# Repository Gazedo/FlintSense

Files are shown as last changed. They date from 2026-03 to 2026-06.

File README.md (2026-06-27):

# FlintMesh — Wildfire Early Warning Sensor Network

A distributed, solar-powered LoRa sensor network that measures fire-weather
conditions in real time.  Nodes report data compatible with the
[Fire Weather Index (FWI)](https://cwfis.cfs.nrcan.gc.ca/background/summary/fwi) and
[NFDRS](https://www.wfas.net/index.php/nfdrs-fire-danger-model-fire-danger-8) frameworks
used by land managers and fire agencies.

Built in Rust — `no_std` Embassy async firmware on ESP32 nodes, `std` gateway on
Raspberry Pi.

---

## Architecture

```
┌─────────────────────────────────────────────────────────────┐
│                        LoRa Mesh                            │
│                                                             │
│   [Sensor Node] ──LoRa──▶ [Bridge Node] ──LoRa──▶ [Gateway] │
│   (flint-node)           (flint-bridge)         (flint-   │
│                                                    gateway) │
└─────────────────────────────────────────────────────────────┘
         │                                        │
         │  Embassy async / no_std                │  std / Tokio
         │  ESP32                                 │  Raspberry Pi
                                                  │
                                           InfluxDB + Grafana
```

Mesh routing uses flood routing with hop-limit deduplication — the same
semantics as [Meshtastic](https://meshtastic.org/).  All packet types and
routing logic live in the shared `flint-proto` crate so embedded nodes and
the gateway always agree on the wire format.

---

## Crates

| Crate | Target | Description |
|---|---|---|
| [`flint-proto`](./flint-proto) | `no_std` (any) | Shared packet types, mesh envelope, seen-packet cache, postcard encode/decode |
| [`flint-bridge`](./flint-bridge) | `xtensa-esp32-none-elf` | LoRa RX + transparent mesh relay + USB binary bridge on Heltec WiFi LoRa 32 V2 |
| [`flint-node`](./flint-node) | `xtensa-esp32-none-elf` | Sensor node firmware on Heltec WiFi LoRa 32 V2 (TX test → real sensors in progress) |
| `flint-gateway` | host (RPi) | Serial reader/decoder for the bridge stream (InfluxDB + Grafana integration planned) |

---

## Sensor Measurements

| Measurement | Sensor | Interface |
|---|---|---|
| Air temperature + relative humidity | SHT40 | I2C 0x44 |
| Barometric pressure | BME280 | I2C |
| Wind speed + direction | Anemometer + vane | GPIO pulse count |
| Dead fuel moisture proxy | Wood dowel + resistive probes | ADC |
| Battery state-of-charge | MAX17048 fuel gauge | I2C 0x36 |

---

## Hardware

### Development (Phase 0) — current
- **Heltec WiFi LoRa 32 V2** — ESP32 + SX1276 + OLED, used for all firmware
  development.  Two boards: one running `flint-node` (TX), one running
  `flint-bridge` (RX + relay + USB bridge).

### Production Node (Phase 1)
- **M5Stack Stamp-C3U** (ESP32-C3, ~5 µA deep sleep) + harvested SX1276
- Custom KiCad PCB: Stamp-C3U + SX1276 + MAX17048 + TP4056 + solar input + sensor headers
- Fabricated at JLCPCB/PCBWay
- 3D-printed weatherproof enclosure

### Gateway
- Raspberry Pi + Heltec V2 as LoRa receiver
- InfluxDB / TimescaleDB for time-series storage
- Grafana dashboard (public)

---

## Getting Started

### Prerequisites

```bash
cargo install espup && espup install   # Xtensa toolchain + export-esp.sh
cargo install espflash
```

Add to `~/.zshrc` (or source before each session):
```bash
. $HOME/export-esp.sh
```

Mac: install the [CP2102 USB driver](https://www.silabs.com/developers/usb-to-uart-bridge-vcp-drivers)
before connecting any board.

### Build

```bash
# Build all crates
cargo build --workspace

# Or a single crate
cargo build -p flint-node
cd flint-bridge && cargo build
```

### Flash & Monitor

Set your USB port in `.cargo/config.toml` (workspace root), then:

```bash
# Flash and open serial monitor
cd flint-node   && cargo run --release
cd flint-bridge && cargo run --release
```

Log output streams over UART via `espflash --monitor`.

### Documentation

```bash
cargo doc --workspace --no-deps --open
```

---

## Bring-up Sequence

| Step | Status | Description |
|---|---|---|
| 1 | ✅ | **Arduino loopback** — confirmed RF link on two Heltec V2 boards |
| 2 | ✅ | **Rust RX ↔ Arduino TX** — `flint-bridge` receiving from factory firmware, validated `lora-phy` config |
| 3 | ✅ | **Full Rust both sides** — `flint-node` TX and `flint-bridge` RX passing `MeshEnvelope` packets end-to-end |
| 4 | 🔄 | **Sensor integration** — fuel moisture (ADC resistive dowel), SHT40 (I2C), MAX17048 (I2C) |
| 5 | ⬜ | **Anemometer pulse counting** — GPIO interrupt task |
| 6 | ⬜ | **RPi gateway** — `flint-gateway` receiving packets, writing to InfluxDB |
| 7 | ⬜ | **SDR passive monitor** — `gr-lora_sdr` chirp waterfall for demos and debugging |

---

## Packet Format

Wire format is [postcard](https://github.com/jamesmunns/postcard)-encoded
`MeshEnvelope<FlintPayload>`, approximately 20–24 bytes per sensor reading.

```
MeshEnvelope {
    from:       u32   // node ID (lower 4 bytes of MAC)
    to:         u32   // 0xFFFFFFFF = broadcast
    packet_id:  u32   // random, used for dedup
    hop_limit:  u8    // decremented on each relay (default 3)
    hop_start:  u8    // original hop_limit
    payload:    FlintPayload::SensorReading {
        node_id:       u8
        temp_c:        i16   // °C × 100
        humidity_pct:  u8
        wind_speed_ms: u8    // m/s × 2
        wind_dir_deg:  u16
        fuel_moisture: u8    // 0–100 %, resistive wood dowel
        battery_soc:   u8
        battery_mv:    u16
        sequence:      u16
    }
}
```

---

## License

MIT OR Apache-2.0

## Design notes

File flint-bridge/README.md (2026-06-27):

# flint-bridge

LoRa receive + transparent mesh relay + **USB bridge** firmware for the
**Heltec WiFi LoRa 32 V2** (ESP32 + SX1276).

`flint-bridge` receives `MeshEnvelope` packets off the air, relays unseen ones,
and **reports every reception to the host over USB as binary records** that
`flint-gateway` decodes with the shared `flint-proto` definitions. The same
record format is what a LoRa radio wired directly into the gateway would emit, so
the host decode path is source-agnostic.

(The crate was formerly `flint-debug`, a human-readable watch tool. Its watch
behaviour now lives in the on-demand **debug mode** below; a standalone watch
tool can be re-created later if wanted.)

## Output modes

The bridge starts in **binary mode** and accepts single-byte commands on USB
serial:

| Command | Mode | Behaviour |
|---|---|---|
| `b` | Binary (default) | Logs suppressed (`set_max_level(Off)`); emits binary `FrameReport`/`RawFrame` records. Clean machine-parseable stream. |
| `d` | Debug | Raises logs to trace; renders frames as human-readable text *instead of* binary — for debugging the bridge itself. |

Commands are idempotent, so a host can send `b` on connect to force a known
state. Unknown bytes are ignored.

## Wire format

Records are defined in `flint-proto` (`bridge` module): a self-delimiting frame
`[sync][tag][len][body][CRC-16]`. `FrameReport` (tag `0x01`) carries link quality
(`rssi`/`snr`/`len`), the receiver's disposition (relayed / local-only /
duplicate), and the received envelope bytes. `RawFrame` (tag `0x02`) carries link
quality plus the raw bytes of any packet that did not decode as a `MeshEnvelope`.
The sync word + length + CRC let the host skip stray boot/panic text and resync.

## Hardware

Heltec WiFi LoRa 32 V2 pin mapping:

| Signal | GPIO |
|---|---|
| SPI SCK | 5 |
| SPI MISO | 19 |
| SPI MOSI | 27 |
| SX1276 CS | 18 |
| SX1276 RST | 14 |
| SX1276 DIO0 | 26 |
| SX1276 DIO1 | 35 |

## Configuration

Before flashing, set your USB port in `.cargo/config.toml`:

```toml
[target.xtensa-esp32-none-elf]
runner = "espflash flash --monitor --baud 921600 --port /dev/cu.usbserial-XXXX"
```

`ESP_LOG = "TRACE"` is set in `.cargo/config.toml` so debug mode can reach trace
level; the runtime gate (`log::set_max_level`) keeps logs off in binary mode.

LoRa modem config (SF / BW / CR / frequency / sync word) is set in `src/main.rs`.
Match these values to your transmitter.

## Build & Flash

```bash
# From workspace root — requires Xtensa toolchain (espup install)
cd flint-bridge
cargo run --release
```

To read the binary stream on the host, run the gateway against the same port:

```bash
cd flint-gateway
cargo run -- /dev/cu.usbserial-XXXX
```

Or send `d` in a serial monitor to eyeball frames directly from the bridge.

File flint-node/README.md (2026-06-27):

# flint-node

LoRa transmit test firmware for the **Heltec WiFi LoRa 32 V2** (ESP32 + SX1276).

Sends a `MeshEnvelope` containing a fake `WeatherPacket` every 5 seconds.
Use alongside `flint-bridge` on a second board to verify the full TX → RX → decode
path before connecting real sensors.

## Hardware

Heltec WiFi LoRa 32 V2 pin mapping:

| Signal | GPIO |
|---|---|
| SPI SCK | 5 |
| SPI MISO | 19 |
| SPI MOSI | 27 |
| SX1276 CS | 18 |
| SX1276 RST | 14 |
| SX1276 DIO0 | 26 |
| OLED SDA | 4 |
| OLED SCL | 15 |
| OLED RST | 16 |

## Configuration

Set your USB port in `.cargo/config.toml`:

```toml
[target.xtensa-esp32-none-elf]
runner = "espflash flash --monitor --baud 921600 --port /dev/cu.usbserial-XXXX"
```

LoRa modem settings (`LORA_FREQUENCY_HZ`, `LORA_SF`, `LORA_BW`, `LORA_CR`) are
constants at the top of `src/main.rs` and **must match** the values in
`flint-bridge` exactly.

`NODE_ADDR` and `NODE_ID` are hardcoded test values. When real sensor hardware
is added these will be derived from the chip MAC address.

## Build & Flash

```bash
# From the flint-node directory
cargo run --release
```

Requires the Xtensa ESP32 Rust toolchain (`espup install`).
The `rust-toolchain.toml` in the workspace root pins the correct toolchain
automatically.

## OLED output

```
FlintNode TX
TX: 3
```

Counter increments after each successful transmission.

## Serial output

```
INFO flint-node booting
INFO TX loop — 915000000Hz  SF7  BW125KHz  CR4_5  5000ms interval
INFO TX seq=0 (N bytes)
INFO TX seq=1 (N bytes)
...
```

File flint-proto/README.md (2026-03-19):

# flint-proto

Shared packet types and mesh routing primitives for the FlintSense sensor
network.

This crate is `no_std` and is a dependency of every other crate in the
workspace — embedded sensor nodes, the debug/relay node, and the Raspberry Pi
gateway all use the same types to guarantee wire-format compatibility.

## Contents

| Item | Description |
|---|---|
| `WeatherPacket` | Fire-weather sensor reading (temperature, humidity, wind, fuel moisture, battery) |
| `FlintPayload` | Enum of all application-layer message types |
| `MeshEnvelope` | Flood-routing wrapper — same hop-limit semantics as Meshtastic |
| `SeenCache` | Fixed-capacity ring cache for seen-packet deduplication |
| `encode` / `decode` | postcard serialization helpers |

## Feature Flags

| Feature | Description |
|---|---|
| `defmt` | Derives `defmt::Format` on all public types for RTT logging on embedded targets |

## Generating Docs

```bash
cargo doc -p flint-proto --open
```

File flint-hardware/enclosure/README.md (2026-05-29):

# FlintMesh Sensor Enclosure

Parametric Build123d model for the FlintMesh outdoor weatherproof sensor enclosure.
Mounts to a 2-inch steel pole. Designed for Nampa, Idaho conditions — intense heat,
high UV, and strong wind gusts.

---

## Components

| File exported | Description | Print notes |
|---|---|---|
| `enclosure_body.stl` | Main box, open top | PETG or ASA — UV stable |
| `lid.stl` | Flat lid with skirt | PETG or ASA |
| `pole_clamp_half.stl` | One half of split-ring clamp | Print × 2 |
| `solar_bracket.stl` | South-facing tilted panel mount | PETG or ASA |
| `anemometer_mount.stl` | 1-inch post stub + flange | PETG |
| `rain_sensor_bracket.stl` | L-bracket with forward tilt | PETG |

---

## Dependencies

```
build123d >= 0.10.0
bd-warehouse >= 0.2.0
```

Install with uv (recommended — already in `pyproject.toml`):

```bash
cd flint-hardware
uv sync
```

Or with pip:

```bash
pip install build123d bd-warehouse
```

For live 3D preview in VS Code, install the OCP CAD Viewer extension:

```bash
pip install ocp_vscode
```

---

## Running

Export all STL and STEP files to `enclosure/exports/`:

```bash
cd flint-hardware
uv run python enclosure/flint_enclosure.py
```

For live preview while editing in VS Code with the OCP CAD Viewer extension,
add this to the bottom of a scratch script:

```python
from ocp_vscode import show
from enclosure.flint_enclosure import build_assembly
show(build_assembly(explode=True))
```

---

## Modifying Parameters

Every dimension is defined in the `Params` dataclass at the top of
`flint_enclosure.py`. Nothing is hard-coded in the geometry functions.

To change a value, edit the relevant sub-dataclass default:

```python
# Make the enclosure taller
@dataclass(frozen=True)
class _EnclosureParams:
    height: float = 90.0  # was 75.0
```

Or override at call time without touching the defaults:

```python
from enclosure.flint_enclosure import build_enclosure_body, Params, _EnclosureParams

custom = Params(enc=_EnclosureParams(height=90.0, width=150.0))
body = build_enclosure_body(custom)
```

---

## Fastener Reference

All fasteners are metric with captive hex nuts. Nothing requires a nut to be
held from inside the enclosure during field assembly.

| Location | Fastener | Nut |
|---|---|---|
| Lid to body (× 4) | M3 × 12 SHCS | M3 hex captive in body boss |
| PCB standoffs (× 4) | M3 × 10 SHCS | Tapped boss |
| Anemometer flange (× 4) | M4 × 20 SHCS | M4 hex captive in lid |
| Solar bracket feet (× 4) | M4 × 16 SHCS | M4 hex captive in lid |
| Solar panel to bracket (× 4) | M4 × 16 SHCS | M4 hex captive in bracket |
| Pole clamp halves (× 2) | M5 × 45 SHCS | M5 hex captive in ear tab |
| Rain sensor (× 4) | M3 × 12 SHCS | M3 hex captive in wall |

SHCS = Socket Head Cap Screw

---

## Design Rationale

### Louver vents
Blades are angled 45° below horizontal — the same principle as a Stevenson
screen used in professional weather stations. Rain cannot drive straight
through, but air circulates freely past the BME680. Vent area is centred on
the middle third of each long wall to avoid the wetter lower zone near the
ground.

### Solar tilt
35° from horizontal. Nampa, ID sits at approximately 43.5°N latitude. Fixed
tilt equal to latitude maximises annual yield; the 35° value is slightly
below latitude to bias toward summer output when irradiance is highest and
the heat load on the electronics is greatest.

### Pole clamp
Split-ring design. One half is permanently attached to the enclosure rear
wall (four M4 screws); the second half is a field piece. Tightening the two
M5 clamp bolts cinches the ring around the pole. The ring wall is 8 mm thick
which provides enough contact area to resist wind loading without cracking
printed PETG.

### Material
ASA is preferred over PETG for all exterior-facing parts (body, lid, solar
bracket). ASA is significantly more UV stable and dimensionally stable at
high ambient temperatures — both important in Nampa summers. PETG is
acceptable for sheltered parts (pole clamp interior, rain sensor bracket if
mounted on the shaded side).

---

## Future Expansion

The file is structured so that new components are additive. To add a new
mount or bracket:

1. Add a `_MyNewParams` dataclass in the Parameters section
2. Add a `my_new_field: _MyNewParams = _MyNewParams()` line to `Params`
3. Write a `build_my_component(p: Params) -> Compound` function following
   the same pattern as the existing builders
4. Add it to `build_assembly()` and `export_all()`

Planned future components (not yet modelled):
- Hinged front access door with gasket groove
- Separate battery compartment tray
- Wind vane (direction) mount alongside anemometer
- Secondary conduit entry on side wall
- Version 2 pole clamp with stainless U-bolt option

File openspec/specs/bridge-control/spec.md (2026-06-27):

# bridge-control Specification

## Purpose

Defines how the host controls the `flint-bridge` output mode over the USB serial
link, including the binary/debug mode command channel and the behaviour of each
mode.

## Requirements

### Requirement: Host-to-device command channel

`flint-bridge` SHALL listen on the USB serial port for single-byte commands from
the host while continuing to receive LoRa frames. The byte `b` selects binary
output mode and the byte `d` selects debug output mode. Commands MUST be
idempotent — sending the byte for the current mode leaves the bridge in that
mode — so a reconnecting host can force a known state. Unrecognised bytes MUST be
ignored without disrupting frame reception.

#### Scenario: Host selects debug mode

- **WHEN** the host sends `d` over serial
- **THEN** the bridge enters debug mode

#### Scenario: Host forces binary mode

- **WHEN** the host sends `b` while already in binary mode
- **THEN** the bridge remains in binary mode and continues emitting binary records

#### Scenario: Unknown command is ignored

- **WHEN** the host sends a byte other than `b` or `d`
- **THEN** the bridge ignores it and continues receiving and reporting frames

### Requirement: Binary mode is the default and silences logs

`flint-bridge` SHALL start in binary mode. In binary mode it MUST set the runtime
log level so that `info!`/`trace!` output is suppressed and does not interleave
with the binary record stream, and it MUST emit `FrameReport`/`RawFrame` binary
records for received frames.

#### Scenario: Logs do not pollute the binary stream

- **WHEN** the bridge is in binary mode (its default at boot) and a frame is
  received
- **THEN** no human-readable log line is written to serial and only the binary
  record(s) for that frame are emitted

### Requirement: Debug mode emits human-readable output with trace logging

In debug mode `flint-bridge` SHALL raise the runtime log level to trace and emit
human-readable frame text *in place of* the binary record stream, so the bridge
itself can be debugged. Switching back to binary mode MUST restore log
suppression and binary records.

#### Scenario: Debug mode shows frames and trace logs

- **WHEN** the bridge is in debug mode and a frame is received
- **THEN** it emits human-readable text for that frame and firmware log output up
  to trace level is enabled, and no binary records are emitted

#### Scenario: Returning to binary mode restores the clean stream

- **WHEN** the bridge is in debug mode and the host sends `b`
- **THEN** the bridge suppresses logs again and resumes emitting binary records

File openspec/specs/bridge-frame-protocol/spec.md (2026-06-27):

# bridge-frame-protocol Specification

## Purpose

Defines the self-delimiting binary record protocol that `flint-bridge` emits over
USB serial and that `flint-gateway` decodes, including framing, integrity checks,
decoded frame reports, raw frame reports, and frame disposition.

## Requirements

### Requirement: Self-delimiting framing with integrity check

The bridge protocol SHALL define a self-delimiting binary record so a host parser
can locate record boundaries, resynchronise after dropped or corrupt bytes, and
reject damaged records. Each record MUST begin with a fixed sync word, carry a
type tag and a body length, and end with a CRC trailer computed over the record
body. The encode and decode of this framing MUST live in `flint-proto` so the
device producer and host consumer share one definition.

#### Scenario: Host resynchronises after stray bytes

- **WHEN** the stream contains non-record bytes before a record (e.g. boot text
  or a panic backtrace) or the parser joins mid-record
- **THEN** the parser can scan forward to the next sync word and decode the next
  complete record

#### Scenario: Corrupt record is rejected

- **WHEN** a record's CRC does not match its body
- **THEN** the parser rejects that record rather than emitting corrupt field
  values

### Requirement: Decoded frame report record

`flint-bridge` SHALL emit exactly one `FrameReport` record, identified by its
type tag, for every received LoRa packet that decodes as a `MeshEnvelope`. The
record MUST carry the link quality (`rssi`, `snr`, byte `len`), the receiver's
disposition of the frame, and the envelope contents in a form the host can decode
with `flint-proto` (e.g. the encoded envelope bytes).

#### Scenario: Sensor reading is received

- **WHEN** a received packet decodes as a `MeshEnvelope` carrying a
  `FlintPayload::SensorReading`
- **THEN** `flint-bridge` emits one `FrameReport` record from which the host can
  recover the link quality, the disposition, and every envelope/sensor field

### Requirement: Frame disposition

Each `FrameReport` SHALL indicate how the receiver disposed of the frame:
relayed onward, delivered locally only, or discarded as a duplicate.

#### Scenario: Frame is relayed

- **WHEN** a decoded frame is unseen and has `hop_limit > 0` and is rebroadcast
- **THEN** its `FrameReport` marks the frame as relayed with the decremented hop
  count that was transmitted

#### Scenario: Frame is local-only

- **WHEN** a decoded frame is unseen and has `hop_limit == 0`
- **THEN** its `FrameReport` marks the frame as locally delivered with no relay

#### Scenario: Frame is a duplicate

- **WHEN** a decoded frame's `packet_id` is already in the seen cache
- **THEN** its `FrameReport` marks the frame as a discarded duplicate and the
  frame is not relayed

### Requirement: Raw frame report record

`flint-bridge` SHALL emit exactly one `RawFrame` record, identified by a type tag
distinct from `FrameReport`, for every received LoRa packet that fails to decode
as a `MeshEnvelope`, carrying the link quality and the raw received bytes, so the
host observes every reception.

#### Scenario: Undecodable packet is received

- **WHEN** a received packet does not decode as a `MeshEnvelope`
- **THEN** `flint-bridge` emits one `RawFrame` record with the link quality and
  the raw bytes, distinguishable by tag from a `FrameReport`

### Requirement: Host decoder in the gateway

`flint-gateway` SHALL read the bridge stream from the serial port, decode records
using the `flint-proto` definitions, and present them. It MUST distinguish record
types and skip non-record bytes without aborting.

#### Scenario: Gateway decodes a live stream

- **WHEN** the gateway is connected to a `flint-bridge` emitting binary records
- **THEN** it decodes each `FrameReport` and `RawFrame`, renders it, and
  continues past any stray bytes between records

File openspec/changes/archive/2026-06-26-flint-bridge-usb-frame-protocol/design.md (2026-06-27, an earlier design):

## Context

`flint-debug` runs on the Heltec WiFi LoRa 32 V2 (ESP32 + SX1276). It receives
LoRa `MeshEnvelope` packets, logs them with `esp-println` over UART0 (CP2102 USB,
921600 baud), and relays unseen packets. There is exactly **one** USB serial
stream, already shared by `esp-println` logs and `esp-backtrace` panic output.

The goal is to feed live mesh traffic into the host as parseable data. The crate
is being repurposed from *debugger* to *bridge* (renamed `flint-bridge`). The
shared `flint-proto` crate (`no_std`, used on node, bridge, and the std gateway)
already owns the air protocol (`MeshEnvelope`, `FlintPayload`, `decode`/`encode`,
`SeenCache`) and is the natural home for the new host-facing record format.

## Goals / Non-Goals

**Goals:**
- A stable, self-delimiting **binary** record format the host can parse and
  resync, defined once in `flint-proto`.
- The same decode path works whether bytes come from `flint-bridge` over USB or,
  later, from a LoRa radio wired directly into the gateway.
- A clean default wire (binary only) with an on-demand human-readable debug mode
  for debugging the bridge itself, toggled over serial.
- A working host reader in `flint-gateway`.

**Non-Goals:**
- Full Meshtastic interop / protobuf migration (already tracked separately in
  `flint-proto`).
- Bidirectional mesh control / downlink to nodes (the command byte is the seed of
  a host→device channel, but only mode control is in scope here).
- Persisting/forwarding frames beyond pretty-printing in the gateway.
- A reusable standalone `flint-debug` watch tool (may be re-created later).

## Decisions

### Binary records over a text line protocol
Chosen so the gateway can later ingest a raw radio with the *same* decoder — the
wire format becomes the contract and the byte source is interchangeable. Text
lines were considered (trivially coexist with logs, human-debuggable) but they
would force the host to re-parse fields and would not match a future radio path.
Bandwidth is irrelevant either way (SF7, infrequent packets), so the radio-reuse
argument decides it. Human-readability is recovered as a *mode*, not the default.

### Framing: sync word + tag + length + body + CRC
A record is `[sync][type tag][len][body][CRC]`. The sync word lets a parser scan
to the next boundary; `len` bounds the body; the CRC (e.g. CRC-16/CCITT) rejects
corruption. This is necessary because the binary stream is **not** clean — see
the panic-bypass risk below — so the parser must tolerate and skip arbitrary
non-record bytes. COBS framing was considered; sync+len+CRC is simpler to specify
and to decode on the host and is robust enough given infrequent records.

### Record bodies reuse the air protocol
`FrameReport` body = a small header (`rssi`, `snr`, `len`, `disposition`) followed
by the **encoded envelope bytes**, so the host recovers all envelope/sensor
fields via the existing `flint_proto::decode`. The only genuinely new fields are
link quality and disposition (neither lives in the envelope). `RawFrame` body =
the same link-quality header plus the raw received bytes (for packets that do not
decode). Two distinct type tags separate the variants. This avoids duplicating
the sensor schema in a second struct.

### One mode switch drives both format and log noise
Output mode is a single state: `Binary` (default) or `Debug`. The `log` crate's
runtime `log::set_max_level()` is the gate:
- `Binary` → `set_max_level(Off)`: `info!`/`trace!` short-circuit before reaching
  the logger, so no text pollutes the binary stream; emit binary records.
- `Debug` → `set_max_level(Trace)`: full firmware logs return *and* frames are
  rendered as human text instead of binary — for debugging the bridge.

To make trace actually reachable, `ESP_LOG` must be raised to `TRACE` in
`.cargo/config.toml` (it currently caps `esp-println` at `INFO` at compile time);
the runtime `set_max_level` then gates emission Off↔Trace. Alternatives
considered: a GPIO strap pin (needs physical access, burns a pin, boot-only) and
a compile-time feature (needs a reflash to switch) — both rejected in favour of
the serial command, which also seeds a future host→device channel.

### Command channel: single command byte
The bridge runs a UART RX task; `b` → binary, `d` → debug. Defined as explicit
*set-mode* bytes (not a toggle) so they are idempotent and a reconnecting host
can force a known state. Unknown bytes are ignored. Most host monitors
(`espflash --monitor`, `picocom`, `screen`, and the gateway itself) forward
stdin to the port, so this works during bring-up.

### Reader lives in `flint-gateway`
The codec (record types, framing, CRC, `Display`) lives in `flint-proto` so it is
shared and IO-free (`no_std`, no serial deps). The serial-reading binary lives in
`flint-gateway` (already `std`), which is the eventual real consumer — so the
bring-up tool becomes the gateway's first feature rather than throwaway code, and
`flint-proto` stays a pure library. Co-locating the reader in `flint-proto` (a
feature-gated `[[bin]]` with an optional `serialport` dep) was considered and
rejected to keep the shared crate dependency-clean.

## Risks / Trade-offs

- **Panic/boot text bypasses the log gate** → `esp-backtrace` output and early
  boot text are emitted regardless of `set_max_level`, so the binary stream is
  never guaranteed clean. *Mitigation:* this is exactly why framing uses
  sync word + length + CRC; the host skips non-record bytes and resyncs. It is an
  argument *for* the framing, not a defect.
- **Mode switch changes the stream format mid-flight** → a host parser reading
  binary will see human text appear after a `d`. *Mitigation:* debug mode is for a
  human at a terminal, not for the parser; the gateway reader runs the bridge in
  binary mode. The set-mode bytes let the gateway assert binary on connect.
- **Crate rename churn** → the directory/bin/README rename touches paths and any
  references (`Makefile`, root docs). *Mitigation:* it is a standalone workspace;
  grep for `flint-debug` references and update them as part of the rename task.
- **CRC/sync choices must match on both ends** → divergence silently drops every
  record. *Mitigation:* both ends call the same `flint-proto` encode/decode; add a
  host-side round-trip unit test over the codec.

## Open Questions

- Exact sync word and CRC variant (e.g. CRC-16/CCITT-FALSE) — settle in
  implementation; must be identical on both ends and tested.
- Whether `disposition` should also distinguish "relay attempted but TX failed"
  from "relayed", or fold TX errors into logs only.

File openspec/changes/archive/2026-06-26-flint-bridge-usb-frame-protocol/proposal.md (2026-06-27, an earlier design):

## Why

The `flint-debug` crate was built to *watch* the mesh during bring-up — it logs
received packets as human-readable text over USB serial. That is the wrong shape
for the next step: feeding live mesh traffic into the host-side gateway as data.
Human-formatted log lines have no delimiters, no integrity check, and interleave
with framework/panic noise, so they cannot be parsed reliably. The crate's role
is changing from *debugger* to *bridge*: receive LoRa frames and report them to
the host in a stable binary form that the gateway can consume — and that a raw
LoRa radio attached directly to the gateway could later produce with the same
decode path.

## What Changes

- **Rename** the `flint-debug` crate to **`flint-bridge`** to reflect its new
  role (LoRa → host bridge). The Heltec V2 receiver/relay behaviour is retained;
  the *output* changes. A fresh `flint-debug` can be written later if a pure
  watch tool is wanted again.
- Add a **binary bridge protocol** in `flint-proto`: a self-delimiting framed
  record with a sync word, a **type tag**, a length, a body, and a CRC trailer so
  a host can locate records and reject corruption. Two record types:
  - `FrameReport` (tag): link quality (`rssi`/`snr`/`len`), disposition
    (relayed / local-only / duplicate), and the decoded envelope bytes.
  - `RawFrame` (tag): link quality plus the raw received bytes for packets that
    do not decode as a `MeshEnvelope`.
- Add a **host→device command channel**: the bridge listens on USB serial for a
  single command byte. `b` selects **binary mode** (default), `d` selects
  **debug mode**.
- **Default to binary, silence logs:** in binary mode the firmware sets the
  runtime log level to off so `info!`/`trace!` cannot pollute the binary stream.
  In debug mode it raises the level to trace and emits human-readable frame text
  *in place of* the binary stream — for debugging the bridge itself.
- Add a **reader to `flint-gateway`**: open the serial port, decode the binary
  bridge stream with `flint-proto`, and pretty-print frames. This becomes the
  gateway's first real feature and the host-side decoder for bring-up.

## Capabilities

### New Capabilities
- `bridge-frame-protocol`: The binary, self-delimiting record format
  (`flint-proto`) that `flint-bridge` emits per reception, including the decoded
  and raw record types and the framing/integrity rules a host relies on.
- `bridge-control`: The host→device command-byte channel and the output-mode /
  log-level semantics it governs (binary vs. debug).

### Modified Capabilities
<!-- No existing specs in openspec/specs/; nothing to modify. -->

## Impact

- **Code**: `flint-debug/` → `flint-bridge/` (crate rename: dir, `Cargo.toml`,
  bin name, README); `flint-bridge/src/main.rs` (emit binary records, add UART
  command-RX task, runtime log gating); `flint-proto/src/lib.rs` (new bridge
  record types + framing/CRC encode + host decode + `Display`); `flint-gateway`
  (serial reader/pretty-printer); `flint-bridge/.cargo/config.toml`
  (`ESP_LOG = "TRACE"`).
- **Consumers**: `flint-gateway` gains a working ingest path; the same decode
  path can later accept bytes from a radio wired directly to the gateway.
- **Dependencies**: `flint-gateway` adds a host serial crate (e.g.
  `serialport`); `flint-proto` gains no new *required* deps (no_std, IO-free).
- **Hardware/flashing**: no pin or modem-config changes; same `espflash` flow.

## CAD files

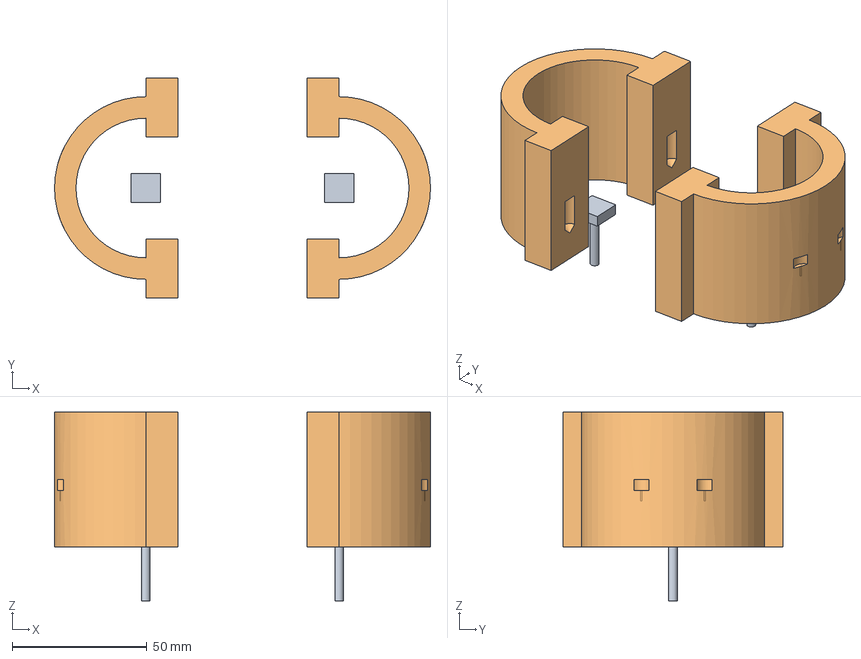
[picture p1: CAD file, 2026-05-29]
flint-hardware/enclosure/exports/pole_clamp_assembly.step
139.6 x 81.8 x 70.0 mm

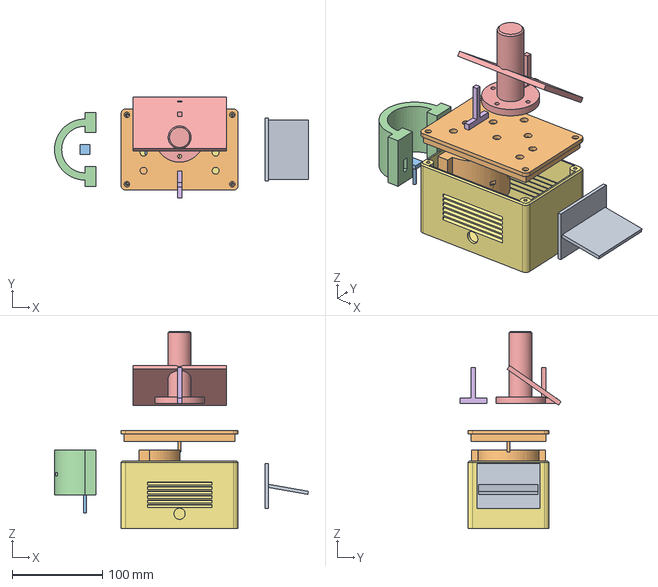
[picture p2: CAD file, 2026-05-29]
flint-hardware/enclosure/exports/assembly_exploded.step
282.0 x 112.6 x 219.0 mm

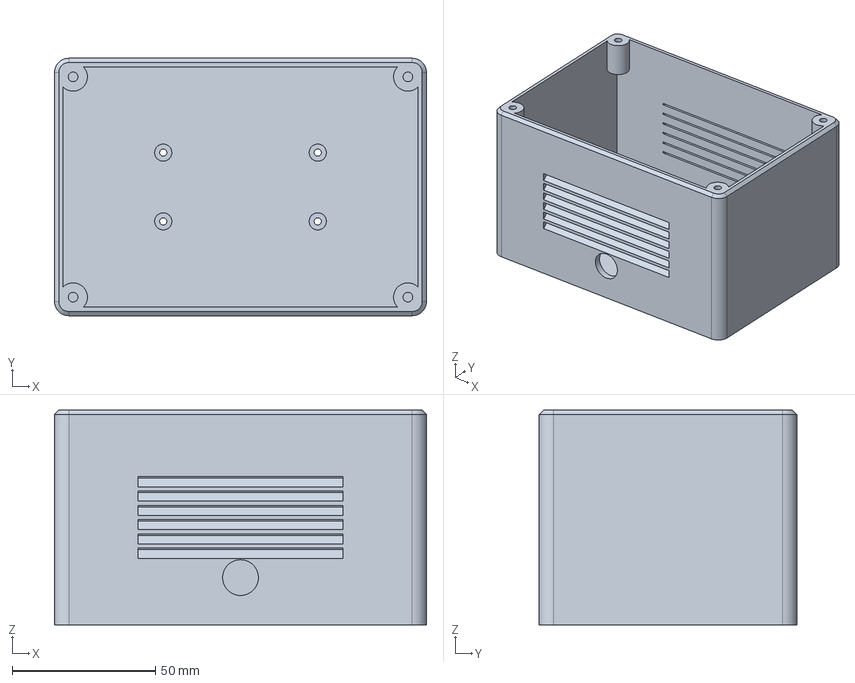
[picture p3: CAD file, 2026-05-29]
flint-hardware/enclosure/exports/enclosure_body.step
130.0 x 90.0 x 75.0 mm

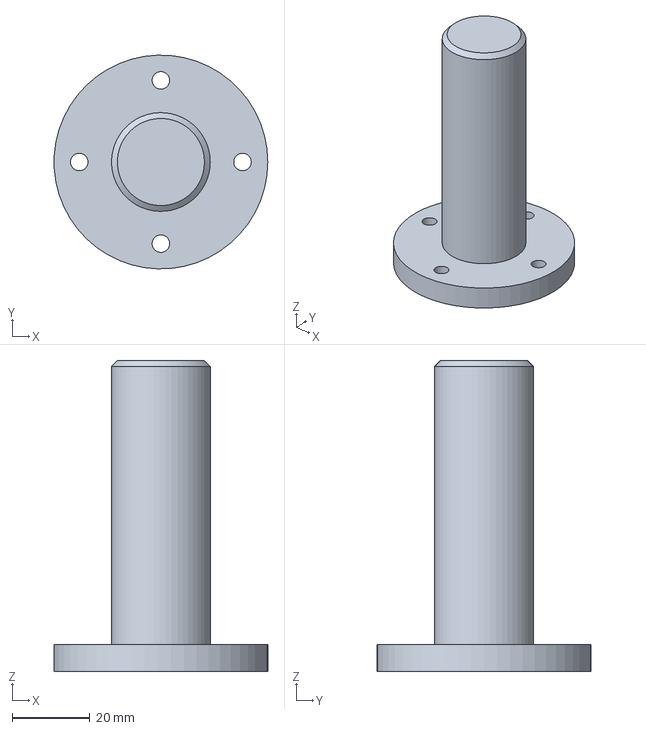
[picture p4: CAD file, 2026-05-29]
flint-hardware/enclosure/exports/anemometer_mount.step
54.9 x 55.0 x 80.0 mm

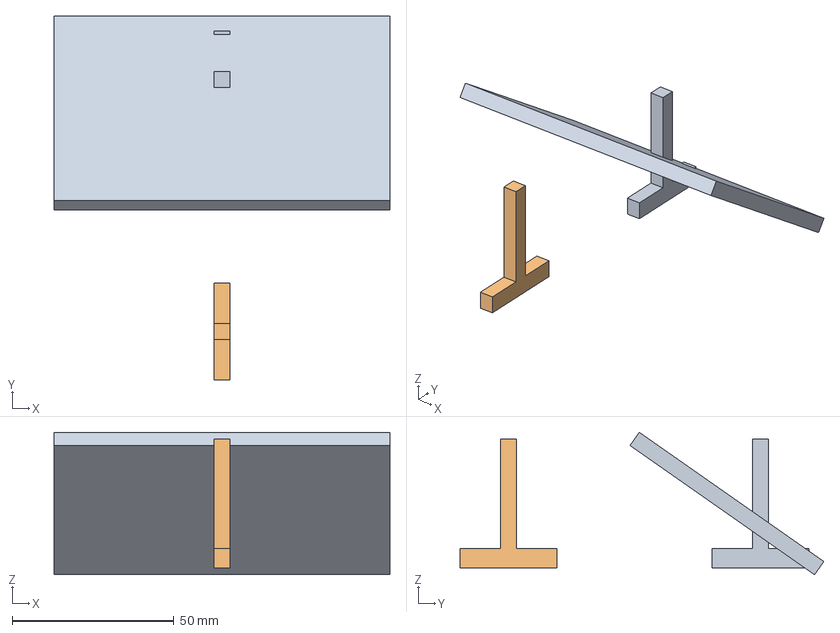
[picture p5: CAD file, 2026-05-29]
flint-hardware/enclosure/exports/solar_bracket.step
104.0 x 112.6 x 44.1 mm

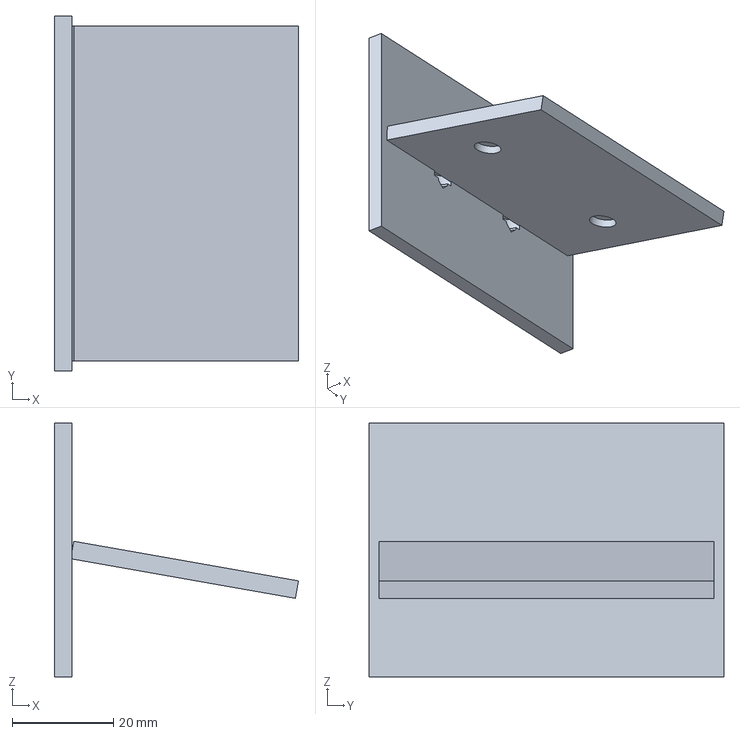
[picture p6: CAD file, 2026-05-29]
flint-hardware/enclosure/exports/rain_sensor_bracket.step
48.1 x 70.0 x 50.0 mm

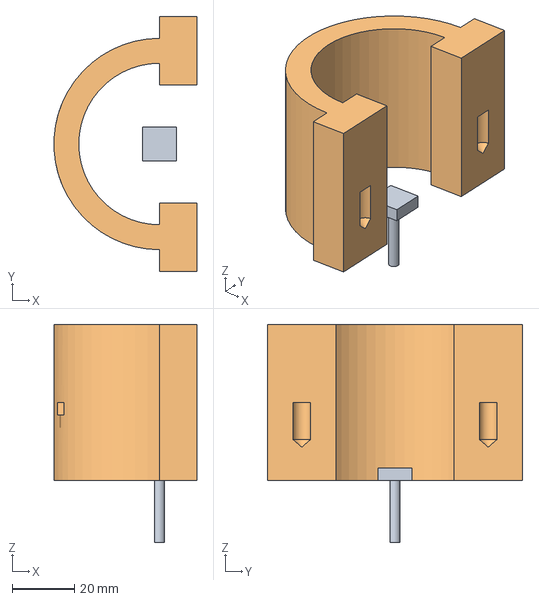
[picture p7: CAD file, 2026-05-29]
flint-hardware/enclosure/exports/pole_clamp_half.step
45.8 x 81.8 x 70.0 mm

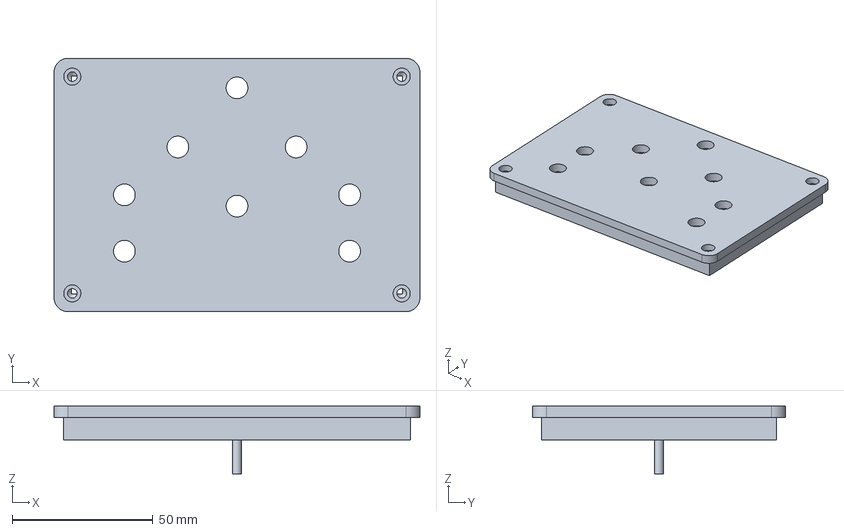
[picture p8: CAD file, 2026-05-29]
flint-hardware/enclosure/exports/lid.step
130.0 x 90.0 x 24.0 mm

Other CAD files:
flint-hardware/enclosure/exports/anemometer_mount.stl
flint-hardware/enclosure/exports/assembly_exploded.stl
flint-hardware/enclosure/exports/enclosure_body.stl
flint-hardware/enclosure/exports/lid.stl
flint-hardware/enclosure/exports/pole_clamp_assembly.stl
flint-hardware/enclosure/exports/pole_clamp_half.stl
flint-hardware/enclosure/exports/rain_sensor_bracket.stl
flint-hardware/enclosure/exports/solar_bracket.stl

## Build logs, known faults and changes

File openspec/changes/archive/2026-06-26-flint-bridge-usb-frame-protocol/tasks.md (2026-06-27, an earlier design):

## 1. Rename crate to flint-bridge

- [x] 1.1 Rename the `flint-debug/` directory to `flint-bridge/`
- [x] 1.2 Update `Cargo.toml`: package `name`, `[[bin]]` name/path, and the
  `description` to reflect the LoRa→host bridge role
- [x] 1.3 Update `README.md` title/description from debug firmware to bridge
- [x] 1.4 Grep the repo for `flint-debug` references (root docs, `Makefile`,
  README) and update them
- [x] 1.5 Confirm the renamed crate still builds (`cargo check` from the crate
  dir on the `xtensa` toolchain passes; flashing covered by 5.2)

## 2. Bridge protocol in flint-proto

- [x] 2.1 Define a `Disposition` enum (relayed / local-only / duplicate)
- [x] 2.2 Define the link-quality header (`rssi`, `snr`, `len`) shared by both
  record types
- [x] 2.3 Define the two record types (`FrameReport`, `RawFrame`) with distinct
  type tags
- [x] 2.4 Implement framing: `[sync][tag][len][body][CRC]` — pick a sync word and
  CRC variant (e.g. CRC-16/CCITT) as constants
- [x] 2.5 Implement device-side `encode` of each record into a caller buffer
  (no_std, no alloc); `FrameReport` body embeds the encoded envelope bytes
- [x] 2.6 Implement host-side `decode`: scan to sync word, validate length + CRC,
  return the record or a recoverable framing error; skip non-record bytes
- [x] 2.7 Add `Display` (or a format helper) for human-readable rendering of each
  record, reused by both the gateway and the bridge's debug mode
- [x] 2.8 Add a round-trip unit test (encode → decode) and a resync test
  (garbage bytes before a valid record)

## 3. Bridge firmware output + control

- [x] 3.1 Set `ESP_LOG = "TRACE"` in `flint-bridge/.cargo/config.toml`
- [x] 3.2 Add an `OutputMode` state (Binary default / Debug) shared with the RX
  loop
- [x] 3.3 At boot, set mode Binary and call `log::set_max_level(Off)`
- [x] 3.4 In the RX loop, on a decoded `MeshEnvelope` emit a `FrameReport` with
  the correct `Disposition` (relayed / local-only / duplicate)
- [x] 3.5 In the RX loop, on an undecodable packet emit a `RawFrame`
- [x] 3.6 In Debug mode, render records as human-readable text instead of binary
  and ensure trace logs are enabled
- [x] 3.7 Add a UART RX task that reads command bytes: `b` → Binary +
  `set_max_level(Off)`, `d` → Debug + `set_max_level(Trace)`, other bytes ignored
- [x] 3.8 Verify commands are idempotent and frame reception continues while
  listening for commands (idempotent by construction — set-mode bytes + concurrent
  embassy task; runtime behaviour validated on hardware)

## 4. Gateway reader

- [x] 4.1 Add a host serial dependency (e.g. `serialport`) to `flint-gateway`
- [x] 4.2 Open the serial port and feed bytes through the `flint-proto` decoder,
  skipping non-record bytes
- [x] 4.3 Pretty-print each `FrameReport`/`RawFrame` using the shared `Display`
  helper, including link quality and disposition
- [x] 4.4 Send `b` on connect to assert binary mode
- [x] 4.5 Manually verify end-to-end: bridge → USB → gateway decodes a live
  `SensorReading`, and a `RawFrame` for noise/Arduino packets (validated on hardware)

## 5. Verification

- [x] 5.1 Run `flint-proto` codec tests (round-trip + resync)
- [x] 5.2 Flash the renamed `flint-bridge`, confirm binary-by-default stream is
  clean (no log text) and `d`/`b` toggles human/binary with trace logs
  (validated on hardware)
- [x] 5.3 Update READMEs/docs describing the bridge protocol and the gateway
  reader usage

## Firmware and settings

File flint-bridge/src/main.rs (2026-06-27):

//! flint-bridge — LoRa receive + mesh relay + USB bridge for Heltec WiFi LoRa 32 V2.
//!
//! Receives `MeshEnvelope` packets off the air, relays unseen ones, and reports
//! every reception to the host over USB as self-delimiting binary records (see
//! `flint-proto`'s `bridge` module). `flint-gateway` decodes the stream.
//!
//! Two tasks: `main` runs the radio + USB, and `display_task` owns the OLED and
//! redraws from a channel. Everything is async — UART (`write_async`), radio, and
//! the OLED I2C (`flush().await`) — so each yields the cooperative executor. A
//! *blocking* I2C flush in a task would stall the executor and break the radio.
//!
//! ## Heltec V2 pin mapping
//!
//!   SPI2 (SX1276): SCK GPIO5  MISO GPIO19  MOSI GPIO27  CS GPIO18  RST GPIO14  DIO0 GPIO26
//!   I2C0 (OLED):   SDA GPIO4  SCL GPIO15   RST GPIO16
//!   UART0 (USB):   TX GPIO1   (CP2102 bridge)

#![no_std]
#![no_main]

use core::fmt::Write as _;

use embassy_executor::Spawner;
use embassy_sync::{blocking_mutex::raw::CriticalSectionRawMutex, channel::Channel};
use embassy_time::{Delay, Instant, Timer};
use embedded_graphics::{
    mono_font::{MonoTextStyle, MonoTextStyleBuilder, ascii::FONT_5X8},
    pixelcolor::BinaryColor,
    prelude::*,
    primitives::{Line, PrimitiveStyle},
    text::{Baseline, Text},
};
use embedded_hal_bus::spi::ExclusiveDevice;
use esp_backtrace as _;
use esp_hal::{
    Async,
    gpio::{Input, InputConfig, Level, Output, OutputConfig, Pull},
    i2c::master::{Config as I2cConfig, I2c},
    spi::{
        Mode,
        master::{Config as SpiConfig, Spi},
    },
    time::Rate,
    timer::timg::TimerGroup,
    uart::{Config as UartConfig, UartTx},
};
use flint_proto::{
    BRIDGE_MAX_FRAME, Disposition, FlintPayload, LinkQuality, MAX_PACKET_BYTES, SeenCache, decode,
    encode, encode_frame_report, encode_raw_frame,
};
use heapless::String;
use lora_phy::{
    LoRa, RxMode,
    iv::GenericSx127xInterfaceVariant,
    mod_params::{Bandwidth, CodingRate, SpreadingFactor},
    sx127x::{Config as Sx127xConfig, Sx127x, Sx1276},
};
use ssd1306::{I2CDisplayInterface, Ssd1306Async, mode::BufferedGraphicsModeAsync, prelude::*};

esp_bootloader_esp_idf::esp_app_desc!();

// ── LoRa channel config ───────────────────────────────────────────────────────
//
// Match these to your transmitter (Arduino-LoRa library defaults shown):
//   LoRa.begin(915E6)              → LORA_FREQUENCY_HZ = 915_000_000
//   LoRa.setSpreadingFactor(7)     → SpreadingFactor::_7
//   LoRa.setSignalBandwidth(125E3) → Bandwidth::_125KHz
//   LoRa.setCodingRate4(5)         → CodingRate::_4_5
//   LoRa.setSyncWord(0x12)         → use_public_network = false

const LORA_FREQUENCY_HZ: u32 = 915_000_000;
const LORA_SF: SpreadingFactor = SpreadingFactor::_7;
const LORA_BW: Bandwidth = Bandwidth::_125KHz;
const LORA_CR: CodingRate = CodingRate::_4_5;
const LORA_PUBLIC_NETWORK: bool = false;
const LORA_TX_POWER_DBM: i32 = 14;

/// Concrete type of the buffered OLED over async I2C.
type Oled = Ssd1306Async<
    I2CInterface<I2c<'static, Async>>,
    DisplaySize128x64,
    BufferedGraphicsModeAsync<DisplaySize128x64>,
>;

/// Details of the most recent decoded reception, for the OLED.
struct MsgRx {
    node_id: u32,
    rssi: i16,
    timestamp_s: u64,
    packet_id: u32,
    temp_c: i16,
    humidity: u8,
    wind_speed_ms: u8,
    gas_ohms: u32,
    battery_soc: u8,
}

/// Display update events. Counts are authoritative (from the RX loop) and carried
/// in every event, so a dropped event only skips a redraw, never miscounts.
enum DisplayEvent {
    Decoded { decoded: u32, errors: u32, msg: MsgRx },
    Counts { decoded: u32, errors: u32 },
}

static DISPLAY: Channel<CriticalSectionRawMutex, DisplayEvent, 8> = Channel::new();

// ── USB output ────────────────────────────────────────────────────────────────

/// Write all bytes to the USB UART (async).
async fn usb_write_all(usb_tx: &mut UartTx<'static, Async>, bytes: &[u8]) {
    let mut sent = 0;
    while sent < bytes.len() {
        match usb_tx.write_async(&bytes[sent..]).await {
            Ok(0) => break,
            Ok(n) => sent += n,
            Err(_) => break,
        }
    }
}

/// Emit a decoded reception as a binary `FrameReport`.
async fn report_frame(
    usb_tx: &mut UartTx<'static, Async>,
    link: &LinkQuality,
    disposition: Disposition,
    hops_left: u8,
    envelope_bytes: &[u8],
) {
    let mut frame = [0u8; BRIDGE_MAX_FRAME];
    if let Ok(n) = encode_frame_report(link, disposition, hops_left, envelope_bytes, &mut frame) {
        usb_write_all(usb_tx, &frame[..n]).await;
    }
}

/// Emit an undecodable reception as a binary `RawFrame`.
async fn report_raw(usb_tx: &mut UartTx<'static, Async>, link: &LinkQuality, raw: &[u8]) {
    let mut frame = [0u8; BRIDGE_MAX_FRAME];
    if let Ok(n) = encode_raw_frame(link, raw, &mut frame) {
        usb_write_all(usb_tx, &frame[..n]).await;
    }
}

// ── Display task ──────────────────────────────────────────────────────────────

#[embassy_executor::task]
async fn display_task(mut display: Oled) {
    let mut decoded = 0u32;
    let mut errors = 0u32;
    let mut last: Option<MsgRx> = None;

    render(&mut display, decoded, errors, &last).await;

    loop {
        match DISPLAY.receive().await {
            DisplayEvent::Decoded {
                decoded: d,
                errors: e,
                msg,
            } => {
                decoded = d;
                errors = e;
                last = Some(msg);
            }
            DisplayEvent::Counts {
                decoded: d,
                errors: e,
            } => {
                decoded = d;
                errors = e;
            }
        }
        render(&mut display, decoded, errors, &last).await;
    }
}

/// Layout (128×64):
///
///   FlintBridge RX12 ERR0      ← title + metrics on one line (FONT_5X8)
///   ─────────────────────────
///   Pkt deadbeef               ← packet id, spans both columns
///   Node 7   │ T 23.50C        ← two columns
///   RSSI -91 │ H 42%
///   Time 5s  │ W 7.0
///   Batt 88% │ Gas 51234
async fn render(display: &mut Oled, decoded: u32, errors: u32, last: &Option<MsgRx>) {
    let font: MonoTextStyle<BinaryColor> = MonoTextStyleBuilder::new()
        .font(&FONT_5X8)
        .text_color(BinaryColor::On)
        .build();
    let rule = PrimitiveStyle::with_stroke(BinaryColor::On, 1);

    display.clear(BinaryColor::Off).ok();

    let mut buf: String<28> = String::new();

    // ── Header: title + metrics on one line ──
    let _ = write!(buf, "FlintBridge RX{decoded} ERR{errors}");
    Text::with_baseline(buf.as_str(), Point::new(0, 0), font, Baseline::Top)
        .draw(display)
        .ok();
    Line::new(Point::new(0, 10), Point::new(127, 10))
        .into_styled(rule)
        .draw(display)
        .ok();

    if let Some(m) = last {
        // ── Packet id header (spans both columns) ──
        buf.clear();
        let _ = write!(buf, "Pkt {:08x}", m.packet_id);
        Text::with_baseline(buf.as_str(), Point::new(0, 12), font, Baseline::Top)
            .draw(display)
            .ok();

        // Column divider
        Line::new(Point::new(63, 21), Point::new(63, 63))
            .into_styled(rule)
            .draw(display)
            .ok();

        let rows = [22, 32, 42, 52];
        let cell = |display: &mut Oled, x: i32, row: usize, text: &str| {
            Text::with_baseline(text, Point::new(x, rows[row]), font, Baseline::Top)
                .draw(display)
                .ok();
        };

        // Left column: packet/link metrics
        buf.clear();
        let _ = write!(buf, "Node {}", m.node_id);
        cell(display, 0, 0, buf.as_str());
        buf.clear();
        let _ = write!(buf, "RSSI {}", m.rssi);
        cell(display, 0, 1, buf.as_str());
        buf.clear();
        let _ = write!(buf, "Time {}s", m.timestamp_s);
        cell(display, 0, 2, buf.as_str());
        buf.clear();
        let _ = write!(buf, "Batt {}%", m.battery_soc);
        cell(display, 0, 3, buf.as_str());

        // Right column: sensor readings
        buf.clear();
        let _ = write!(buf, "T {}.{:02}C", m.temp_c / 100, m.temp_c.unsigned_abs() % 100);
        cell(display, 67, 0, buf.as_str());
        buf.clear();
        let _ = write!(buf, "H {}%", m.humidity);
        cell(display, 67, 1, buf.as_str());
        buf.clear();
        let _ = write!(buf, "W {}.{}m/s", m.wind_speed_ms / 2, (m.wind_speed_ms % 2) * 5);
        cell(display, 67, 2, buf.as_str());
        buf.clear();
        let _ = write!(buf, "Gas {}", m.gas_ohms);
        cell(display, 67, 3, buf.as_str());
    } else {
        Text::with_baseline("waiting for RX...", Point::new(0, 14), font, Baseline::Top)
            .draw(display)
            .ok();
    }

    display.flush().await.ok();
}

// ── Entry point ───────────────────────────────────────────────────────────────

#[esp_rtos::main]
async fn main(spawner: Spawner) {
    let peripherals = esp_hal::init(esp_hal::Config::default());

    let timg0 = TimerGroup::new(peripherals.TIMG0);
    esp_rtos::start(timg0.timer0);

    // ── USB serial output (UART0 TX on GPIO1, async). ─────────────────────────

    let mut usb_tx = UartTx::new(
        peripherals.UART0,
        UartConfig::default().with_baudrate(921_600),
    )
    .expect("UART0 init failed")
    .with_tx(peripherals.GPIO1)
    .into_async();

    // ── OLED (SSD1306 128×64 via async I2C0, SDA=GPIO4, SCL=GPIO15, RST=GPIO16) ─

    let mut oled_rst = Output::new(peripherals.GPIO16, Level::High, OutputConfig::default());
    oled_rst.set_low();
    Timer::after_millis(10).await;
    oled_rst.set_high();
    Timer::after_millis(10).await;

    let i2c = I2c::new(peripherals.I2C0, I2cConfig::default())
        .unwrap()
        .with_sda(peripherals.GPIO4)
        .with_scl(peripherals.GPIO15)
        .into_async();

    let interface = I2CDisplayInterface::new(i2c);
    let mut display = Ssd1306Async::new(interface, DisplaySize128x64, DisplayRotation::Rotate0)
        .into_buffered_graphics_mode();
    display.init().await.unwrap();
    spawner.spawn(display_task(display)).ok();

    // ── SPI2 for SX1276 ──────────────────────────────────────────────────────

    let cs = Output::new(peripherals.GPIO18, Level::High, OutputConfig::default());

    let spi = Spi::new(
        peripherals.SPI2,
        SpiConfig::default()
            .with_frequency(Rate::from_mhz(1))
            .with_mode(Mode::_0),
    )
    .unwrap()
    .with_sck(peripherals.GPIO5)
    .with_miso(peripherals.GPIO19)
    .with_mosi(peripherals.GPIO27)
    .into_async();

    // ExclusiveDevice wraps SpiBus + CS pin into the SpiDevice trait lora-phy needs.
    let spi_dev = ExclusiveDevice::new(spi, cs, Delay).unwrap();

    // ── SX1276 interface variant (reset + DIO0 IRQ) ───────────────────────────

    let reset = Output::new(peripherals.GPIO14, Level::High, OutputConfig::default());
    let dio0 = Input::new(
        peripherals.GPIO26,
        InputConfig::default().with_pull(Pull::Down),
    );

    let iv = GenericSx127xInterfaceVariant::new(reset, dio0, None, None).unwrap();

    // ── Radio init ────────────────────────────────────────────────────────────

    let sx_config = Sx127xConfig {
        chip: Sx1276,
        tcxo_used: false,
        tx_boost: false,
        rx_boost: false,
    };

    let mut lora = LoRa::new(Sx127x::new(spi_dev, iv, sx_config), LORA_PUBLIC_NETWORK, Delay)
        .await
        .expect("LoRa init failed — check SPI wiring and pin assignments");

    let mdm = lora
        .create_modulation_params(LORA_SF, LORA_BW, LORA_CR, LORA_FREQUENCY_HZ)
        .expect("invalid modulation params");
    let rx_params = lora
        .create_rx_packet_params(8, false, MAX_PACKET_BYTES as u8, true, false, &mdm)
        .expect("invalid rx packet params");
    let mut tx_params = lora
        .create_tx_packet_params(8, false, true, false, &mdm)
        .expect("invalid tx packet params");

    let mut seen = SeenCache::new();

    // Boot banner over USB (plain ASCII; the gateway skips it and resyncs on the
    // first framed record). A visible sign of life that TX works.
    {
        let mut banner: String<64> = String::new();
        let _ = write!(banner, "flint-bridge ready: {}Hz SF{}\r\n", LORA_FREQUENCY_HZ, LORA_SF as u8);
        usb_write_all(&mut usb_tx, banner.as_bytes()).await;
    }

    let mut decoded_count: u32 = 0;
    let mut error_count: u32 = 0;

    // ── Main receive loop ─────────────────────────────────────────────────────

    loop {
        if lora
            .prepare_for_rx(RxMode::Continuous, &mdm, &rx_params)
            .await
            .is_err()
        {
            continue;
        }

        let mut rx_buf = [0u8; MAX_PACKET_BYTES];
        let (len, status) = match lora.rx(&rx_params, &mut rx_buf).await {
            Ok(r) => r,
            Err(_) => continue,
        };

        let raw = &rx_buf[..len as usize];
        let link = LinkQuality {
            rssi: status.rssi as i16,
            snr: status.snr as i16,
            len: len as u8,
        };

        match decode(raw) {
            Ok(envelope) => {
                let (disposition, hops_left) = if seen.check_and_insert(envelope.packet_id) {
                    match envelope.for_relay() {
                        Some(relay) => {
                            let mut tx_buf = [0u8; MAX_PACKET_BYTES];
                            if let Ok(bytes) = encode(&relay, &mut tx_buf)
                                && lora
                                    .prepare_for_tx(&mdm, &mut tx_params, LORA_TX_POWER_DBM, bytes)
                                    .await
                                    .is_ok()
                            {
                                let _ = lora.tx().await;
                            }
                            (Disposition::Relayed, relay.hop_limit)
                        }
                        None => (Disposition::LocalOnly, 0),
                    }
                } else {
                    (Disposition::Duplicate, 0)
                };

                report_frame(&mut usb_tx, &link, disposition, hops_left, raw).await;

                decoded_count = decoded_count.saturating_add(1);
                let FlintPayload::SensorReading(w) = &envelope.payload;
                let msg = MsgRx {
                    node_id: w.node_id as u32,
                    rssi: link.rssi,
                    timestamp_s: Instant::now().as_millis() / 1000,
                    packet_id: envelope.packet_id,
                    temp_c: w.temp_c,
                    humidity: w.humidity_pct,
                    wind_speed_ms: w.wind_speed_ms,
                    gas_ohms: w.gas_resistance_ohms,
                    battery_soc: w.battery_soc,
                };
                DISPLAY
                    .try_send(DisplayEvent::Decoded {
                        decoded: decoded_count,
                        errors: error_count,
                        msg,
                    })
                    .ok();
            }
            Err(_) => {
                report_raw(&mut usb_tx, &link, raw).await;
                error_count = error_count.saturating_add(1);
                DISPLAY
                    .try_send(DisplayEvent::Counts {
                        decoded: decoded_count,
                        errors: error_count,
                    })
                    .ok();
            }
        }
    }
}

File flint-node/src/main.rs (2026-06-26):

//! flint-node — LoRa transmit firmware for RAK4631 (nRF52840 + SX1262).
//!
//! Sends a MeshEnvelope containing a fake WeatherPacket every 5 seconds.
//! Flash and monitor logs with `cargo run` via probe-rs over SWD (J10 on RAK19007).
//!
//! ## RAK4631 pin mapping
//!
//!   SPI3 (SX1262):  SCK  P1.11  MISO P1.13  MOSI P1.12  NSS  P1.10
//!   SX1262 control: RST  P1.06  DIO1 P1.15  BUSY P1.14
//!   SX1262 RF sw:   TXEN P1.07  RXEN P1.08
//!
//! All pin assignments are declared as named variables at the top of `main`
//! so they are easy to remap for other boards.

#![no_std]
#![no_main]

use defmt::{error, info, warn};
use defmt_rtt as _;
use embassy_executor::Spawner;
use bosch_bme680::{AsyncBme680, Configuration, DeviceAddress};
use embassy_nrf::{
    bind_interrupts,
    gpio::{Input, Level, Output, OutputDrive, Pull},
    peripherals,
    spim::{self, Spim},
    twim::{self, Twim},
};
use embassy_sync::{blocking_mutex::raw::CriticalSectionRawMutex, signal::Signal};
use embassy_time::{Delay, Duration, Timer, with_timeout};
use embedded_hal_bus::spi::ExclusiveDevice;
use flint_proto::{FlintPayload, MAX_PACKET_BYTES, MeshEnvelope, WeatherPacket, encode};
use lora_phy::{
    LoRa,
    iv::GenericSx126xInterfaceVariant,
    mod_params::{Bandwidth, CodingRate, SpreadingFactor},
    sx126x::{Config as Sx126xConfig, Sx126x, Sx1262, TcxoCtrlVoltage},
};

bind_interrupts!(struct Irqs {
    TWISPI0 => twim::InterruptHandler<peripherals::TWISPI0>;
    // Radio SPI on TWISPI1 (SPIM1), matching the lora-phy RAK4631 example. The
    // high-speed SPIM3 instance has clock-domain quirks that gave an intermittent
    // SPI link (GetStatus flapping 0x2a ↔ 0x00); a plain SPIM instance is stable.
    TWISPI1 => spim::InterruptHandler<peripherals::TWISPI1>;
});

/// Panic handler that blinks the green status LED (P1.03) forever.
///
/// `panic-probe` only surfaces a panic when a debug probe is attached; on bare
/// USB / external power its fault is a silent infinite loop, which is exactly
/// what made the cold-boot init failures invisible. Raw register writes are used
/// so this works with no HAL state and no probe.
#[panic_handler]
fn panic(_info: &core::panic::PanicInfo) -> ! {
    const P1_BASE: usize = 0x5000_0300;
    const OUTSET: *mut u32 = (P1_BASE + 0x508) as *mut u32;
    const OUTCLR: *mut u32 = (P1_BASE + 0x50C) as *mut u32;
    const DIRSET: *mut u32 = (P1_BASE + 0x518) as *mut u32;
    const LED: u32 = 1 << 3; // P1.03 (RAK19007 green LED)

    cortex_m::interrupt::disable();
    unsafe {
        core::ptr::write_volatile(DIRSET, LED); // drive P1.03 as output
        loop {
            core::ptr::write_volatile(OUTSET, LED);
            for _ in 0..400_000 {
                cortex_m::asm::nop();
            }
            core::ptr::write_volatile(OUTCLR, LED);
            for _ in 0..400_000 {
                cortex_m::asm::nop();
            }
        }
    }
}

/// Blink the status LED `n` times (~120 ms period) for visual diagnostics while
/// the firmware is still alive (sensor retries, fatal-before-reset, etc.).
async fn blink(led: &mut Output<'_>, n: u8) {
    for _ in 0..n {
        led.set_low();
        Timer::after_millis(60).await;
        led.set_high();
        Timer::after_millis(60).await;
    }
}

/// Mailbox: a request to flash the status LED `n` times. Holds only the latest
/// request (fine for a low-rate TX heartbeat); use a Channel if you need a FIFO.
static BLINK: Signal<CriticalSectionRawMutex, u8> = Signal::new();

/// Perpetual task that owns the status LED and flashes it on request, so the TX
/// loop just fires `BLINK.signal(n)` and moves on without paying the flash time.
#[embassy_executor::task]
async fn led_task(mut led: Output<'static>) {
    led.set_low();
    loop {
        let n = BLINK.wait().await; // parks here at ~0 CPU until signalled
        for _ in 0..n {
            led.set_high();
            Timer::after_millis(30).await;
            led.set_low();
            Timer::after_millis(70).await;
        }
    }
}

// ── LoRa channel config ───────────────────────────────────────────────────────
// Must match the gateway / debug receiver exactly.

const LORA_FREQUENCY_HZ: u32 = 915_000_000;
const LORA_SF: SpreadingFactor = SpreadingFactor::_7;
const LORA_BW: Bandwidth = Bandwidth::_125KHz;
const LORA_CR: CodingRate = CodingRate::_4_5;
const LORA_PUBLIC_NETWORK: bool = false;
const LORA_TX_POWER_DBM: i32 = 14;

/// Hardcoded node identity for this test board.
const NODE_ADDR: u32 = 0x0000_0001;
const NODE_ID: u8 = 1;

/// Interval between transmissions.
const TX_INTERVAL_MS: u64 = 5_000;

// ── Entry point ───────────────────────────────────────────────────────────────
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

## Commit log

2026-05-29 flint-node: integrate BME680 (RAK1906) for real temp/humidity readings
    Wire I2C0 to the WisBlock sensor slot (SDA P0.13, SCL P0.14), initialise
    the AsyncBme680 driver, and read temperature and humidity each TX cycle.
    Replaces the hardcoded placeholder values in WeatherPacket.
    [main.rs]
2026-05-29 flint-electrical: add component datasheets
    Reference PDFs for AO3401A, CN3791, ESP32-C3, HX711, INA219, SX1276.
2026-05-29 flint-hardware: add CadQuery enclosure design and Python tooling
    Parametric enclosure modelled in CadQuery (main.py) with uv-managed deps.
    Exports: body, lid, pole-clamp assembly, anemometer mount, rain sensor and
    solar brackets — all as STEP and STL.
    [anemometer_mount.step, anemometer_mount.stl, assembly_exploded.step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]
2026-05-29 flint-gateway: add initial crate skeleton
    Empty Rust binary crate — will read sensor data from serial, push to
    Weather Underground, and publish to MQTT.
2026-05-29 flint-ui: add Slint dashboard with MQTT support
    Barebones native desktop UI built on Slint 1.x. Subscribes to
    flintmesh/node/+/weather via rumqttc (sync client in a background
    thread), deserialises JSON sensor readings, and updates a per-node
    VecModel on a 100ms Slint timer. Displays temp, humidity, wind,
    fuel moisture, battery, and last-seen time per node.
    Includes per-crate rust-toolchain.toml (stable) and .cargo/config.toml
    (aarch64-apple-darwin) so `cd flint-ui && cargo build` works correctly
    within the workspace whose root defaults to the esp/thumbv7em toolchain.
    Config via env: FLINT_MQTT_HOST, FLINT_MQTT_PORT, FLINT_MQTT_TOPIC_PREFIX.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
    [main.rs]
2026-06-26 chore: clean up repo and split firmware into standalone workspaces
    - Remove tracked .DS_Store files and editor local-history junk
    - Rewrite .gitignore (target, .DS_Store, *.log, .history, Python venv)
    - Delete root .cargo/config.toml that forced thumbv7em on every crate
    - Split flint-node (nRF52840) and flint-debug (ESP32) into standalone
    workspaces; the root workspace now holds only the host crates
    (flint-proto, flint-gateway, flint-ui)
    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
2026-06-26 feat: carry BME680 gas resistance through the air protocol
    Add gas_resistance_ohms (a MOX VOC/smoke proxy) to WeatherPacket and read
    the BME680 gas channel on flint-node into the TX loop. IAQ math is deferred
    to the gateway; update the packet-size accounting.
2026-06-27 feat(flint-bridge): USB frame protocol and gateway reader
    Rename flint-debug to flint-bridge and give it a LoRa->host bridge role.
    Add a self-delimiting binary record protocol in flint-proto
    ([sync][tag][len][body][CRC]) with device-side encode and host-side
    decode/resync. The bridge emits FrameReport records for decoded
    MeshEnvelopes (with link quality and relay disposition) and RawFrame
    records for undecodable packets, defaulting to binary mode with logs
    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
